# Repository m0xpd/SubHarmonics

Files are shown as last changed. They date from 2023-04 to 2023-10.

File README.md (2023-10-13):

# SubHarmonics 

'SubHarmonics' is a Eurorack module which generates two squarewaves ('A' and 'B') which are sub-harmonics of another signal, 'X'.

<p width=100%, align="center">

</p>

The signal X is either  
i) generated by the module's internal Voltage Controlled Oscillator  
or  
ii) is derived from an external signal applied to the module's 'Ext X In' input.

The sub-harmonics are generated by hardware dividers, which divide the frequency of X by integer divisors (m, n) of 2, 4, 6, 8, 10, 12, 14, 16 or 18,
giving the unit a range of a little over four octaves (18 ≈ 2 <sup> 4.17 </sup> ). 

These divisors (m := f <sub> x </sub> / f <sub> A </sub>, n := f <sub> x </sub> / f <sub> B </sub>) are voltage controlled - they can be set by potentiometers or by control voltages applied from external sources.

It is seen that the signals A and B are themselves related in frequency by 'the ratio of two small integers' (m/n). So, in addition to each being 
sub-harmonics of X, the ratio between A and B often falls at a musically useful interval; 
<p align="center">
'SubHarmonics' generates harmony as well as bass.
</p>

Other applications of 'SubHarmonics' in Clock Division and Rhythm Generation are described [here.](https://github.com/m0xpd/SubHarmonics/blob/main/Applications/ClockDivision_and_RhythmGeneration.md)

### Internal Modulators

SubHarmonics includes a pair of internal modulators, which combine the A and B signals together (through an OR and an Exclusive OR operation) to
exploit and develop the harmonic relationship between A and B into a richer sound. The OR modulation is equivalent (for these signals A, B) to simple
amplitude modulation, as performed by (e.g.) an AND gate, whilst the Exclusive OR modulation implements the balanced modulation of A with B (as in a 
'ring modulator'). I described the equivalence of OR and AND gates as modulators for the special class of 'antipalindromic' inputs (such as the present 
A and B signals) at tedious length [here.](http://m0xpd.blogspot.com/2023/03/logic-gates-and-modulation-curiosity.html)

The two different modulation results are combined in a voltage-controlled crossfader circuit (controlled by a potentiometer or an external CV input) 
to give a single output which offers a choice OR A MIX of the modulation types at the 'Mod Mix' output.

An introductory video, demonstrating SubHarmonics' features, is available [here](https://youtu.be/j_IT1Ucp6_4)

### Setup

There are two presets that need adjustment on completion of the module to setup for use. Both are located on the topside of the Main Board.

TR2 (a multi-turn 1k preset) controls the 1V/Octave tracking. It should be set by connecting the module to a reliable source of pitch CV signals and monitoring the outputs. I use octave outputs from a BeatStep Pro (you can use a keyboard with CV pitch outputs or simply a known voltage source) and listen to the pitch change. I find it easy to tune octaves by ear but, if you are uncertain, use a tuner or frequency counter.

TR1 (a single turn 100k preset) controls the balance of the modulation mix crossfader. To set it properly requires access to an oscilloscope to see the 'Mod Mix' output waveform. If you have no access to a 'scope, set TR1 to about 60kΩ.

If you do have a 'scope, set the divisors to m=2, n=6 (using the front panel controls) and the frequency to an arbitrary value (around 300Hz). View the 'A' and 'Mod Mix' outputs on the 'scope. Adjust TR1 until you see these waveforms when you put the Mix control at extreme ends of its travel (or, equivalently, apply 0V or 5V CV signals to the Mix input):

<p align="center", width=100%>

</p>

(the yellow trace is the 'A' output, which stays the same in this setup process and is included only as a 'reference', the blue trace is the 'Mod Mix' output, which will change when you adjust TR1)  

[If you do not see this waveform on the ModMix output with these settings, it may be due to the phase relationship between the dividers - if this is the case, change the value of 'n' using the potentiometer all the way up to 18 and back to 6 and see if the phase is re-aligned. This is perfectly normal and is not a fault - there is another 'mode' of the system in the m=2, n=6 configuration to that illustrated above.]

Note that the 'Mod Mix' output is inverted (it runs 0 to approx -4V); there wasn't a spare op-amp stage to restore polarity after the crossfader. 
This doesn't matter in ordinary applications; the ear is insensitive to the inversion and it will sound the same! There are, however, some implications of this inversion which are important to the 'time-domain' applications discussed [here.](https://github.com/m0xpd/SubHarmonics/blob/main/Applications/ClockDivision_and_RhythmGeneration.md)

### Miscellaneous Details

The sub-harmonic generation and all signal processing is performed in hardware. 

A small (PIC) microcontroller is used to read the potentiometers and CV inputs and set the dividers. 

Details of the two PCBs and front panel are provided in the [Hardware](https://github.com/m0xpd/SubHarmonics/tree/main/Hardware) folder. Code for 
the 16F676 PIC is presented in the [Controller](https://github.com/m0xpd/SubHarmonics/tree/main/Controller) folder.

SubHarmonics is:  
12HP wide,   
requires 38mm behind the front panel (with the power header fitted) and  
draws 13.5mA from the 12V rail and 5mA from the -12V rail.  

The design is published under a Creative Commons CC BY-SA 4.0 [License](https://github.com/m0xpd/SubHarmonics/blob/main/LICENSE.txt).

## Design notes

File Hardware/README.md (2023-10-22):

# Hardware
This folder contains hardware descriptions of the 'SubHarmonics' module.

The information is presented as EAGLE 'sch' and 'brd' files for the two PCBs (in the [PCBs folder](https://github.com/m0xpd/SubHarmonics/tree/main/Hardware/PCBs) ) and as a small Kicad project for the front panel (in
the FrontPanel folder).

SubHarmonics is implemented in two modules, each of which has its own PCB. There is a Main Board, hosting the majority of the electronics and
a Control Board, which contains all the front panel components including the division indicator LEDs and associated decoders.

## Main Board Description

The Main Board schematic is available [here](https://github.com/m0xpd/SubHarmonics/blob/main/Hardware/SubHarmonics%20Main%20Board%20Schematic%20v2.png) (or by clicking on the graphic below)

<p align='center' width=100%>

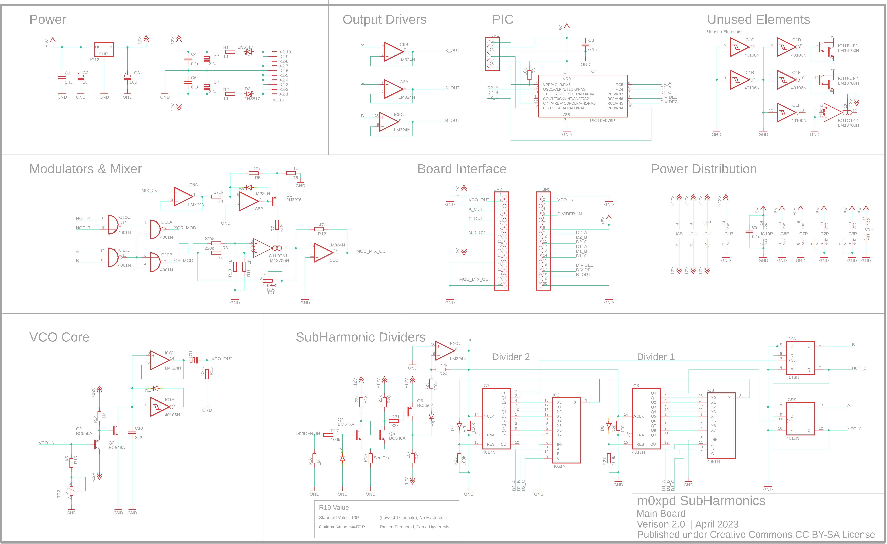
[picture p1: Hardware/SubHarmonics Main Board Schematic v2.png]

</p>

The VCO was inspired by the ['Shapes VCO' design by Moritz Klein](https://www.youtube.com/watch?v=QBatvo8bCa4), subsequently used in his VCO for the [Erica Synths Edu DIY VCO](https://www.ericasynths.lv/shop/diy-kits-1/edu-diy-vco/). Since developing 'SubHarmonics', I have learned that the core of the 40106 VCO was not a Klein original, but had been proposed earlier by Mark Shaner (a.k.a. "Synthmonger"), who published the idea [here](https://electro-music.com/forum/topic-28799.html) back in 2008.

The output of this 'Shaner' 40106 VCO - or the input from an external 'X' source - is applied to the 'Divider_In' input of the SubHarmonic Dividers, the input stages of which produce a 0 : 5V pulse at node 'X' on the schematic. There is a detailed description of the derivation of this pulse signal, including
discussion of options to set shared emitter resistor R19 to either maximise input sensitivity or enable a degree of noise immunity, [here.](https://github.com/m0xpd/SubHarmonics/blob/main/Hardware/Graphics/Input%20Stage%20Switching%20Behaviour.md) 

The system was designed around 'available materials' I found lying around my bench - in this case, mainly CD4000-series CMOS logic devices. 

The divisions in each of the two channels are achieved by a CD4015 (Decade counter) and a CD4051 (Analog Mux/Demux) in conventional 
configuration. The divisor is set by a PIC microcontroller, which reads a potentiometer or a CV input signal and decodes the voltage (0-5V) into 
one-of-8 settings for the dividers.

A further divide-by-2 stage, implemented in a CD4013 (D-type SR flip-flop) applied to the outputs of the dividers adds another octave of division 
(necessary to implement the m=2 setting on the A channel).

The outputs of the dividers, A and B (and their complements, not_A and not_B) are fed to two modulators, implemented in a quad NOR package (CD4001).

The results of the OR and XOR operations are mixed in a voltage-controlled crossfader, implemented in half an LM13700.

The [schematic](https://github.com/m0xpd/SubHarmonics/blob/main/Hardware/SubHarmonics%20Main%20Board%20Schematic%20v2.png) and [BoM](https://github.com/m0xpd/SubHarmonics/blob/main/Hardware/PCBs/SubHarmonics%20Main%20Board%20BoM%20v2.txt) show LM324 quad op-amps. These work fine in this application, but you can substitute the ubiquitous TL074 if you prefer. 

The Main Board includes an In-Circuit Serial Programming (ICSP) interface (JP1) to facilitate programming the PIC.

There is a [.sch](https://github.com/m0xpd/SubHarmonics/blob/main/Hardware/PCBs/SubHarmonics%20Main%20Board%20v2.sch) file, a [.brd](https://github.com/m0xpd/SubHarmonics/blob/main/Hardware/PCBs/SubHarmonics%20Main%20Board%20v2.brd) file and a [BoM](https://github.com/m0xpd/SubHarmonics/blob/main/Hardware/PCBs/SubHarmonics%20Main%20Board%20BoM%20v2.txt) for the Main Board in EAGLE format in the [PCBs folder](https://github.com/m0xpd/SubHarmonics/tree/main/Hardware/PCBs).

## Control Board Description

The Control Board schematic is available [here](https://github.com/m0xpd/SubHarmonics/blob/main/Hardware/Control%20Board%20Schematic.png) (or by clicking on the graphic below)
<p align='center' width=100%>

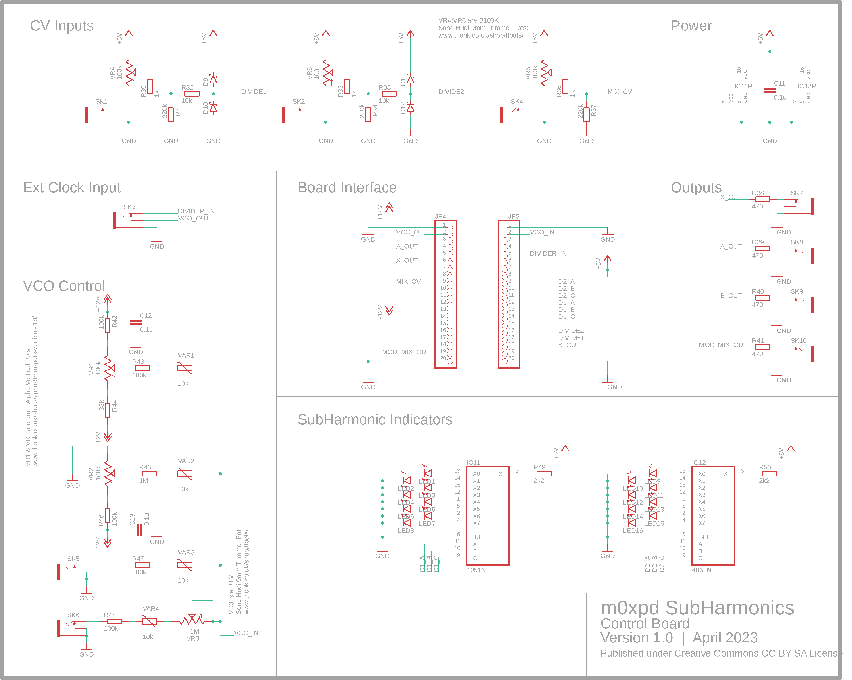
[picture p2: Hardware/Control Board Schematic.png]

</p>

In addition to controls, inputs and outputs, the Control Board hosts the division indicator LEDs and decoders to control these (which again use 
CD4051 analog demuxers).

As well as to CV inputs for Pitch and FM, there are CV inputs for the divisors m and n and for the modulation mix. These last three are designed 
to operate over a range of 0 to 5V, but are protected such that voltages outside these limits will cause no damage.

A 0V input on the modulation mix CV input gives the XOR modulation and a 5V input gives the OR modulation (which is spectrally richer, as it includes the
harmonics of A and B as well as the sum and difference harmonics). An intermediate control voltage gives a mix of both modulation types.

There is a [.sch](https://github.com/m0xpd/SubHarmonics/blob/main/Hardware/PCBs/SubHarmonics%20Control%20Board%20v1.sch) file, a [.brd](https://github.com/m0xpd/SubHarmonics/blob/main/Hardware/PCBs/SubHarmonics%20Control%20Board%20v1.brd) file and a [BoM](https://github.com/m0xpd/SubHarmonics/blob/main/Hardware/PCBs/SubHarmonics%20Control%20Board%20v1%20BoM.txt) for the Control Board in EAGLE format in the [PCBs folder.](https://github.com/m0xpd/SubHarmonics/tree/main/Hardware/PCBs)

The Main and Control boards are joined by two 20-way 0.1 inch pitch headers. These have been specified with electrical redundancy (several pins are 
unused) to provide mechanical stability and security in assembling the module.

The completed PCBs are seen in the photo below, which shows the Main Board from both sides and the Control Board from the 'top' side (the front panel 
components all are mounted on the 'bottom' side).
<p align='center' width=100%>



</p>
 
## Front Panel

<p align='center' width=100%>
SubHarmonics Front Panel

</p>

A simple Kicad project defining a Front Panel for the module is available in the [FrontPanel folder.](https://github.com/m0xpd/SubHarmonics/tree/main/Hardware/FrontPanel)

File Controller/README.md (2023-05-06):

# Controller Code for SubHarmonics

Code for the PIC 16F676 microcontroller is found [here.](https://github.com/m0xpd/SubHarmonics/blob/main/Controller/Divide_Controller.c)

It was developed in C in Microchip's [MPLAB IDE](https://www.microchip.com/en-us/tools-resources/develop/mplab-x-ide).

The [code](https://github.com/m0xpd/SubHarmonics/blob/main/Controller/Divide_Controller.c) should be placed within an MPLAB project for the 16F676, built and programmed into the device using a suitable programmer.

I programmed the first PIC using my [PICKit 3](https://www.microchip.com/en-us/development-tool/PG164130) and my old [k1el PIC Programming Adapter](https://hamcrafters2.com/PICPGM.html), but I designed an In-Circuit Serial Programming 
Interface into the SubHarmonics Main Board, so you can program directly on the module:
<p align='center', width=100%>

</p>

The PICKit3 supplies easily enough current to power the module; no special setting or modification needs to be made to the module during programming.

I will try to post a complete MPLAB project (rather than just the C code) and a .hex file in this repository once I've figured out how to do it.

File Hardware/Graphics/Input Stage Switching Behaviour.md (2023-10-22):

# Input Switching Behaviour

The pulses applied to the SubHarmonics' divider chains are derived from either 
* the internal VCO or
* the "Ext X In" input 

via the input stage formed of Q4 & Q5, Q6 and IC6C.

These active elements amplify the input and form it into a pulse signal, which is saturated at levels of the +/- 12V 
power rails (at the collector of Q6) and subsequently half-wave rectified, inverted and attenuated (by D6 and IC6C)
to pulses of approximately 5V.

The Q4, Q5 stage is a stripped-down version of a conventional transistor [Schmitt Trigger.](https://en.wikipedia.org/wiki/Schmitt_trigger) 

In the present application, the input stage is required to have high sensitivity (a low value of 'HIGH THRESHOLD'), 
as the output of the VCO is rather small (~1.5 V peak). Accordingly, a low magnitude of the emitter resistor 
R19 = 10R was initially chosen in order to obtain a switching threshold of 0.85V.

Unfortunately, this 10R resistor destroys almost all the hysteresis which is the defining property of a Schmitt Trigger.

The images below show the switching behaviour of SubHarmonics with R19 at values of 10R and 470R.

<p width=100%, align="center">
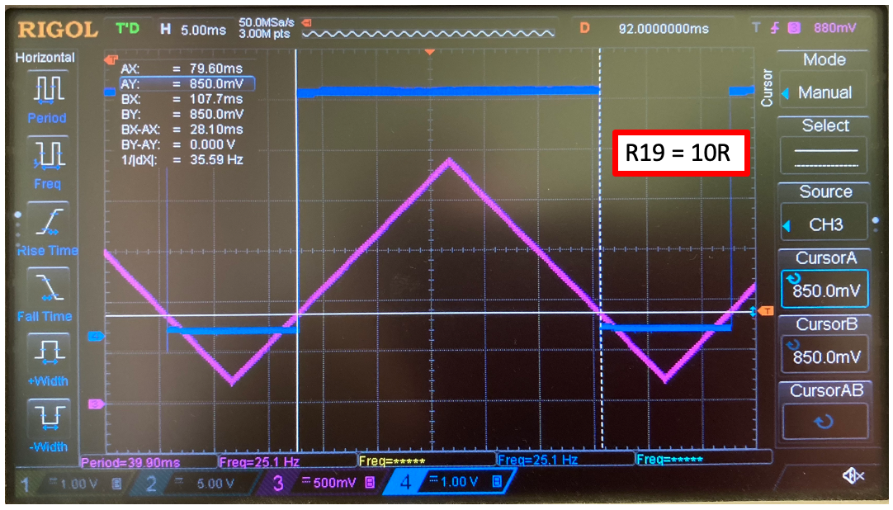
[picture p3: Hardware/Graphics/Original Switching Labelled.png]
 
</p>
<p width=100%, align="center">
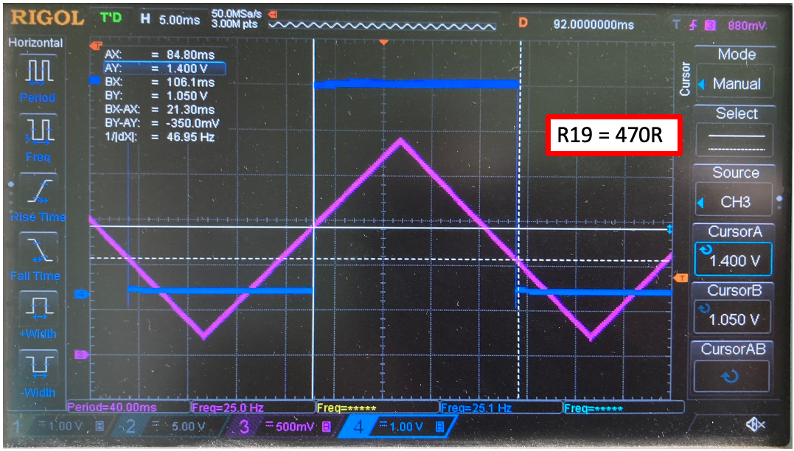
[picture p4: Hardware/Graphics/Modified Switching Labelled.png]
 
</p>

You can see that the 10 Ohm resistor results in switching of the 'X output' (Blue trace) at the same (0.85V) point on the upward 
and downward transistions of the External X input (Cyan trace). The switching point is shown by the 'scope's "A cursor", which 
superimoses a (white) horizontal line on the screen and records a numerical value at top left. The HIGH and LOW THRESHOLDS are 
equal and there is no hysteresis.

The 470 Ohm resistor results in switching at 1.4V on upward transitions of the input (HIGH THRESHOLD = 1.4V, shown by the 'A cursor') 
whilst switching on the downward transition occurs at the lower input voltage of ~1.05V (LOW THRESHOLD = 1.05V, shown by the 'B cursor',
which adds a dashed white horizontal line). There is now approximatey 0.35V of hysteresis.

Although it is possible to further increase the emitter resistor magnitude in other applications (and thereby achieve greater hysteresis),
this is won at the expense of still greater increases in the value of HIGH THRESHOLD. I have found that 470R is the largest 
value that can be used in SubHarmonics in order that the signal from the internal VCO is still detected. 

If we deliberately add 350mV (pk-pk) of noise:

<p width=100%, align="center">
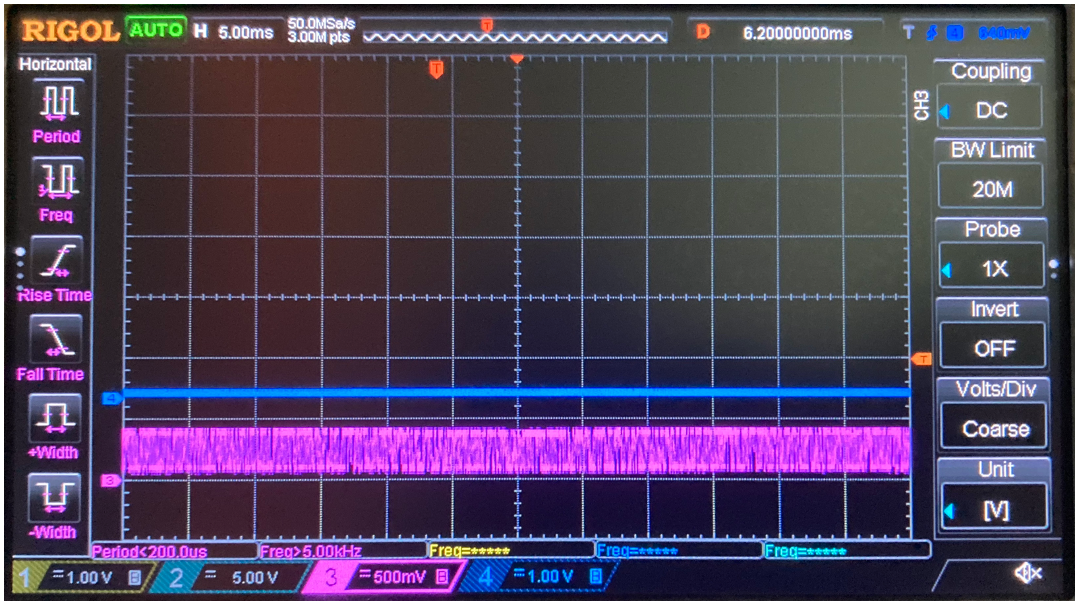
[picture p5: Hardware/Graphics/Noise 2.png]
 
</p>
to the external X input, the potential benefits of the Schmitt Trigger action become clear.

The modified (R19=470R) circuit operates well in the presence of the noise,

<p width=100%, align="center">
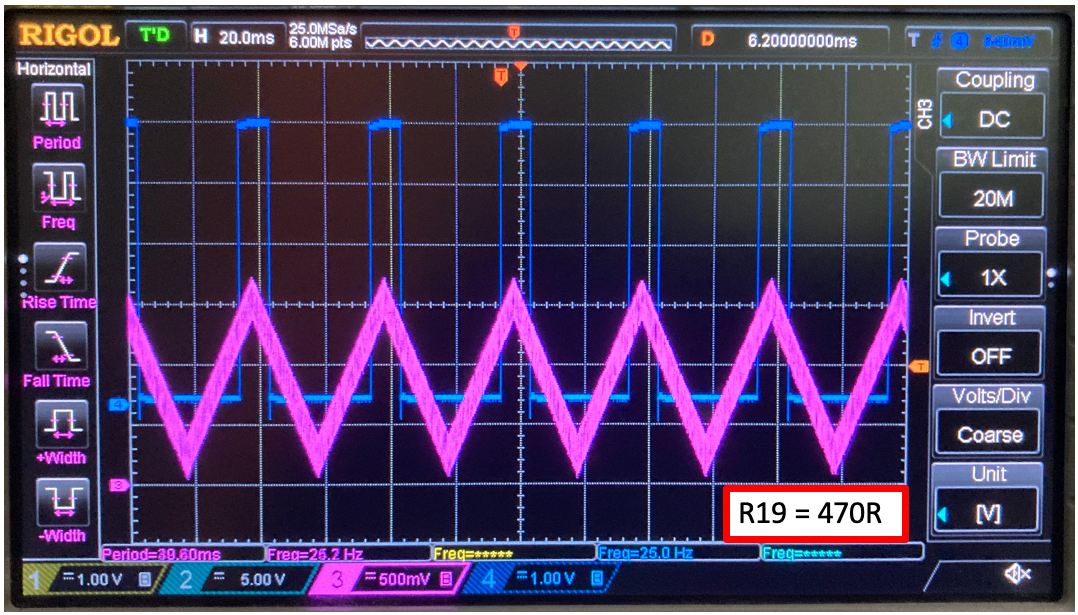
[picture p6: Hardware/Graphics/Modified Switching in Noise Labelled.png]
 
</p>

with nice, clear, regular transitions of the (Blue) X output trace.

However, the circuit in original configuration (R19 = 10R) suffers visible disruption of the (Blue) X output 
with the same noisy external X input
<p width=100%, align="center">
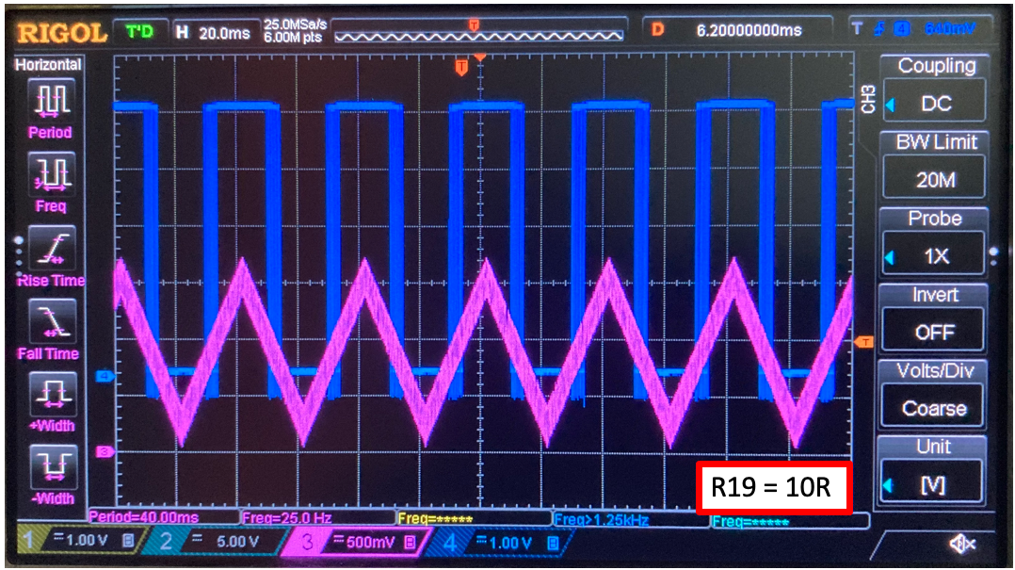
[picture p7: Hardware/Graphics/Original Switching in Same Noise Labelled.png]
 
</p>

This can be made to LOOK more dramatic by reducing the input signal (and keeping the noise amplitude the same). 
<p width=100%, align="center">
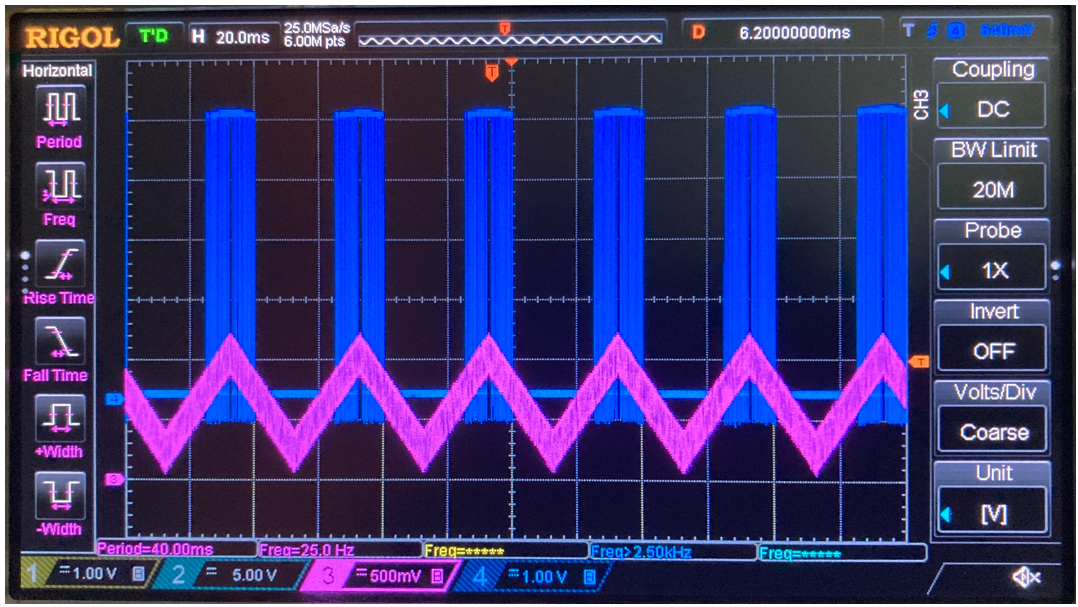
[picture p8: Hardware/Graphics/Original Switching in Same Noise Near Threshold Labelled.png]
 
</p>

Note that it is not the peak 'signal' to noise ratio that is important; rather it is the THRESHOLD to noise ratio. 

What we did most significantly in the figure above was reduce the GRADIENT of the input signal around the 
threshold voltage, so we changed the effective timescale; the system spent more time around the decision point
and there was more opportunity for the noise to cause false triggers, which showed up as visible lines on the 'scope.

# Choosing a value for R19

So, if you build a 'SubHarmonics' module you have a choice.
* you could opt for the original R19 = 10R value, with the best possible input sensitivity (switching threshold = 0.85V), 
but NO Schmitt Trigger action, or
* you could opt for the maximum R19 = 470R value, with a loss of input sensitivity (HIGH THSRESHOLD = 1.4V) and ~0.35V 
Schmitt Trigger 'hysteresis', or
* you could opt for a mid-point compromise.

I have built both versions (R19 = 10R, R19 = 470R). Both work well.

I used the original (R19=10R) for six months and never noticed any problem with noise immunity on the 'Ext X In' input 
which made me wish there was Schmitt Trigger action. However, we are used to having high amplitude, noise-free signals
avaialble from our oscillators, so that's hardly surprising.

On the other hand, now I've enabled the Schmitt Trigger functionality, the same high amplitude oscillator and clock 
signals can still trigger the SubHarmonics module at the 'Ext X In' input but I get the "extra insurance" of 0.35V of 
noise immunity at no additional expense (a 470R resistor is no more expensive than a 10R resistor - or even a wire link!).

So - all things considered - I guess I prefer the revised version with R19 = 470R. 

You must make your own choice.
 
# Acknowledgement

All this interest in the magnitude of R19 and the reinstatement of Schmitt Trigger action was prompted by a question raised
by Yves Chartier, and subsequent discussion. I am grateful for Yves' valuable contribution and support.

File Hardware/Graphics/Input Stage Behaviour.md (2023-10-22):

# SubHarmonics' X Input Stage behaviour

The pulses applied to the harmonic divider chains is derived from either the internal VCO or the External input 
via the input stage formed of Q4 & Q5, Q6 and IC6C.

These active stages amplify the input and form it into a pulse signal, which is saturated at levels of the +/- 12V 
power rails (at the collectro of Q6) and subsequently half-wave rectified, inverted and attenuated (by D6 and IC6C)
to a pulse a little over 5V.

The Q4, Q5 stage is a stripped-down version of a conventional transistor [Schmitt Trigger](https://en.wikipedia.org/wiki/Schmitt_trigger) stage. 

In this applcation, the stage is required to have high sensitivity (a low value of 'HIGH THRESHOLD'), as the output 
of the VCO is rather small (~1.5 V). Accordingly, a low magnitude of the emitter resistor R19 = 10R was initially 
chosen, which gave a switching threshold of 0.85V.

Unfortunately, this 10R resistor destroys almost all the hysteresis which is the defining property of the Schmitt Trigger.

The images below show the switching behaviour of SubHarmonics with R19 at values of 10R and 470R.

<p width=100%, align="center">
 
</p>
<p width=100%, align="center">
 
</p>

You can see that the 10 Ohm resistor results in swithing (of the  (Blue) output at the same (0.85V) point on the upward 
and downward transistions of the (Cyan) input - i.e. the HIGH and LOW THRESHOLDS are equal and there is no hysteresis.

The 470 Ohm resistor results in switching at 1.4V on upward transitions of the input (HIGH THRESHOLD = 1.4V) whilst swithing
on the downward transition occurs at the lower input voltage of ~1.05V (LOW THRESHOLD = 1.05V). There is now approximatey 
0.35V of hysteresis.

Although it is possible to further increse the emitter resistor magnitude in other applications (and achieve greater hysteresis),
this is won at the expense of still greater increases in the value of HIGH THRESHOLD. I have found that 470R is the greatest 
value that can be used in SubHarmonics in order that the signal from the internal VCO is still detected. 

If we deliberately add 350mV of noise:

<p width=100%, align="center">
 
</p>
to the input, the potential benefits of this Schmitt Trigger action become clear.

The modified (R19=470R) circuit operates well in the presence of the noise,

<p width=100%, align="center">
 
</p>

with nice, clear, regular yransitions of the (Blue) output trace.

However, the circuit in original configuration (R19 = 10R) suffers visible disruption of the (Blue) output 
with the same input
<p width=100%, align="center">
 
</p>

This can be made to LOOK more dramatic by reducing the input signal (and keeping the noise amplitude the same). 
<p width=100%, align="center">
 
</p>

Note that it is not the peak 'signal' to noise ratio that is important; rather it is the THRESHOLD to noise ratio. 
What we did most significantly in the figure above was change the GRADIENT of the input signal around the 
threshold voltage, so we changed the effective timescale; the system spent more time around the decision point
and there was more opportunity for the noise to cause false triggers, which showed up as visible lines on the 'scope.

So, if you build a 'SubHarmonics' module you have a choice.
* you could opt for the original R19 = 10R value, with the best possible input sensitivity (switching threshold = 0.85V), 
but NO Schmitt Trigger action, or
* you could opt for the maximum R19 = 470R value, with a loss of input sensitivity (HIGH THSRESHOLD = 1.4V) and ~0.35V 
Schmitt Trigger 'hysteresis', or
* you could opt for a mid-point compromise.

I have built both versions.

I used the original (R19=10R) for six months and never noticed any problem with noise immunity on the 'Ext X In' input 
which made me wish there was Schmitt Trigger action. However, we are used to having high amplitude, noise-free signals
avaialble from our oscillators, so that's hardly surprising.

On the other hand, now I've added the extra Schmitt Trigger functionality, the same high amplitude oscillator and clock 
signals can still trigger the SubHarmonics input but I get the "extra insurance" of 0.35V of noise immunity at no additional
expense (a 470R resistor is no more expensive than a 10R resistor - or even a wire link!).

So - all things considered - I guess I prefer the revised version with R19 = 470R. You must make your own choice.
 
# Acknowledgement

All this interest in the magnitude of R19 and the reinstatement of Schmitt Trigger action was prompted by a question raised
by Yves Chartier, and subsequent discussion. I am grateful for Yves' valuable contribution and support.

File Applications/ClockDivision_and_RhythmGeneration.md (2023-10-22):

If you reduce the frequency of SubHarmonics' VCO or apply a clock signal to the 'Ext X In' from an LFO or similar source,
you enable a range of opportunities in **Clock Division** and **Rhythm Generation**.

## SubHarmonics as a Clock Divider 

The two divider chains of SubHarmonics will offer direct division of the X clock by ratios of:

2, 4, 6, 8, 10, 12, 14 & 16   (for the A output) 

and

4, 6, 8, 10, 12, 14, 16, & 18 (for the B output)

These divisions can be set either by the manual m & n divisor controls or by CV inputs.

Many 'secondary' divisions can be established between A and B outputs. 

For example, with m=2 and n=6 the ratio between X and A is 1:2 and the ratio between X and B is 1:6, 
making the ratio between A and B 2:6 (1:3).

Similarly, other odd integer ratios can be established via this 'secondary' approach, such that all integer ratios up 
to ten can be achieved:

<p width=100%, align="center">

</p>

Similarly, even integer divisions from 10 to 18 can be achieved directly.

## Building Rhythm using SubHarmonics

Given the clock division described above, it is possible to take the divided clock signals and use them to trigger 
percussive sounds, making SubHarmonics a Rhythm Generator. 

The complexity of the rhythms generated is greatly increased if logic operations (AND, OR XOR, etc) are performed between 
the clock signals (X, A & B) to derive more interesting patterns.

Remember that SubHarmonics has it's own pair of internal logic modulators, which combine the A and B signals (through OR 
and XOR functions). These are combined at the 'ModMix' output and can be selected by the 'Mix' control (or by CV). 
This was desiged for use when the ModMix output was interpreted as an 'analog' audio signal (rather than a Boolean switching 
signal). Accorindingly, there are a couple of issues for the present 'Rhythm Generator' application:

1) Signals from the 'ModMix' output are inverted, running from 0 to -3.75V. To use as conventional (positive true) logic 
signals, they must be inverted. I use a Voltage Processor to perform this inversion ('Maths' or any capable processor can 
do the job). You can just shift the level (rather than do an inversion) but this results in a different function - interesting
as it will generate a different pattern and potentially useful if you don't have the resource to do the actual inversion.

2) There is no real meaning in the mixed signals for intermediate settings of the 'Mix' control in this context; the mix 
is only relevant to the output when used in 'analog' applications - so switching between the two modulators is best achieved 
with changes between extreme settings of the 'Mix' control (0 or 5V CV) to give either the XOR or the OR modulator.

The consequence of changing the Mix control is illustrated in this example:

<p width=100%, align="center">

</p>

The 'scope traces show: 
* the X signal (top trace, Yellow)
* the A subharmonic, m=8, (second trace, Cyan)
* the B subharmonic, n=16, (third trace, Blue)
* the Mix output, (bottom trace, Purple)

The left-hand image shows the response with the OR modulator (Mix control fully clockwise or 5V CV Input) and the right-hand 
trace shows the response with the XOR modulator (Mix control fully counter clockwise or 0V CV input).

Finally, AND **MOST IMPORTANTLY**, the two dividers are independant. This allows you to deliberately change the 'phase' between 
the SubHarmonics A & B. This introduces **additional variation in rhythm generation**.

Variation is achieved by briefly changing the setting of one of the divisors (m or n), which introduces a relative delay 
(or advance, depending if you increase or decrease the divisor) relative to the other subharmonic, thereby changing the 
'phase'. 

The process is not deterministic, but you will soon 'get the feel for it'. 

I prefer to adjust the largest divisor (i.e. max(m,n)) by one step for a couple of seconds and listen for the result before returning 
to the nominal value.

There is a video, demonstrating these ideas with two percussion voices, [here](https://youtu.be/6WWO7RoppK4).

The period, T0, of a pattern generated by mixing subharmonics m & n is given by:

T0 = Tx.m.n/*gcd(m,n)*

where Tx is the clock period and *gcd()* is the [greatest common divisor.](https://en.wikipedia.org/wiki/Greatest_common_divisor)

Some examples are tabulated below:

<p width=100%, align="center">

</p>

You can easily set up a reasonably complex rhythm source, with triggers from A, B, logical operations on A and B (I like to 
use an external AND gate driven by A and B, occasionally with extra inputs - as there is no AND modulator internal to SubHarmonics) 
and, of course, ModMix. 

You establish a basic pattern by setting m & n and introduce variation by 
* changing the 'phase' and 
* switching between the internal modulators.

---

**SubHarmonics** can be used to generate 
* melody, using its VCO,
* bass, using its dividers,
* harmony, using its modulators, 
* **and rhythm**, using the process described above.

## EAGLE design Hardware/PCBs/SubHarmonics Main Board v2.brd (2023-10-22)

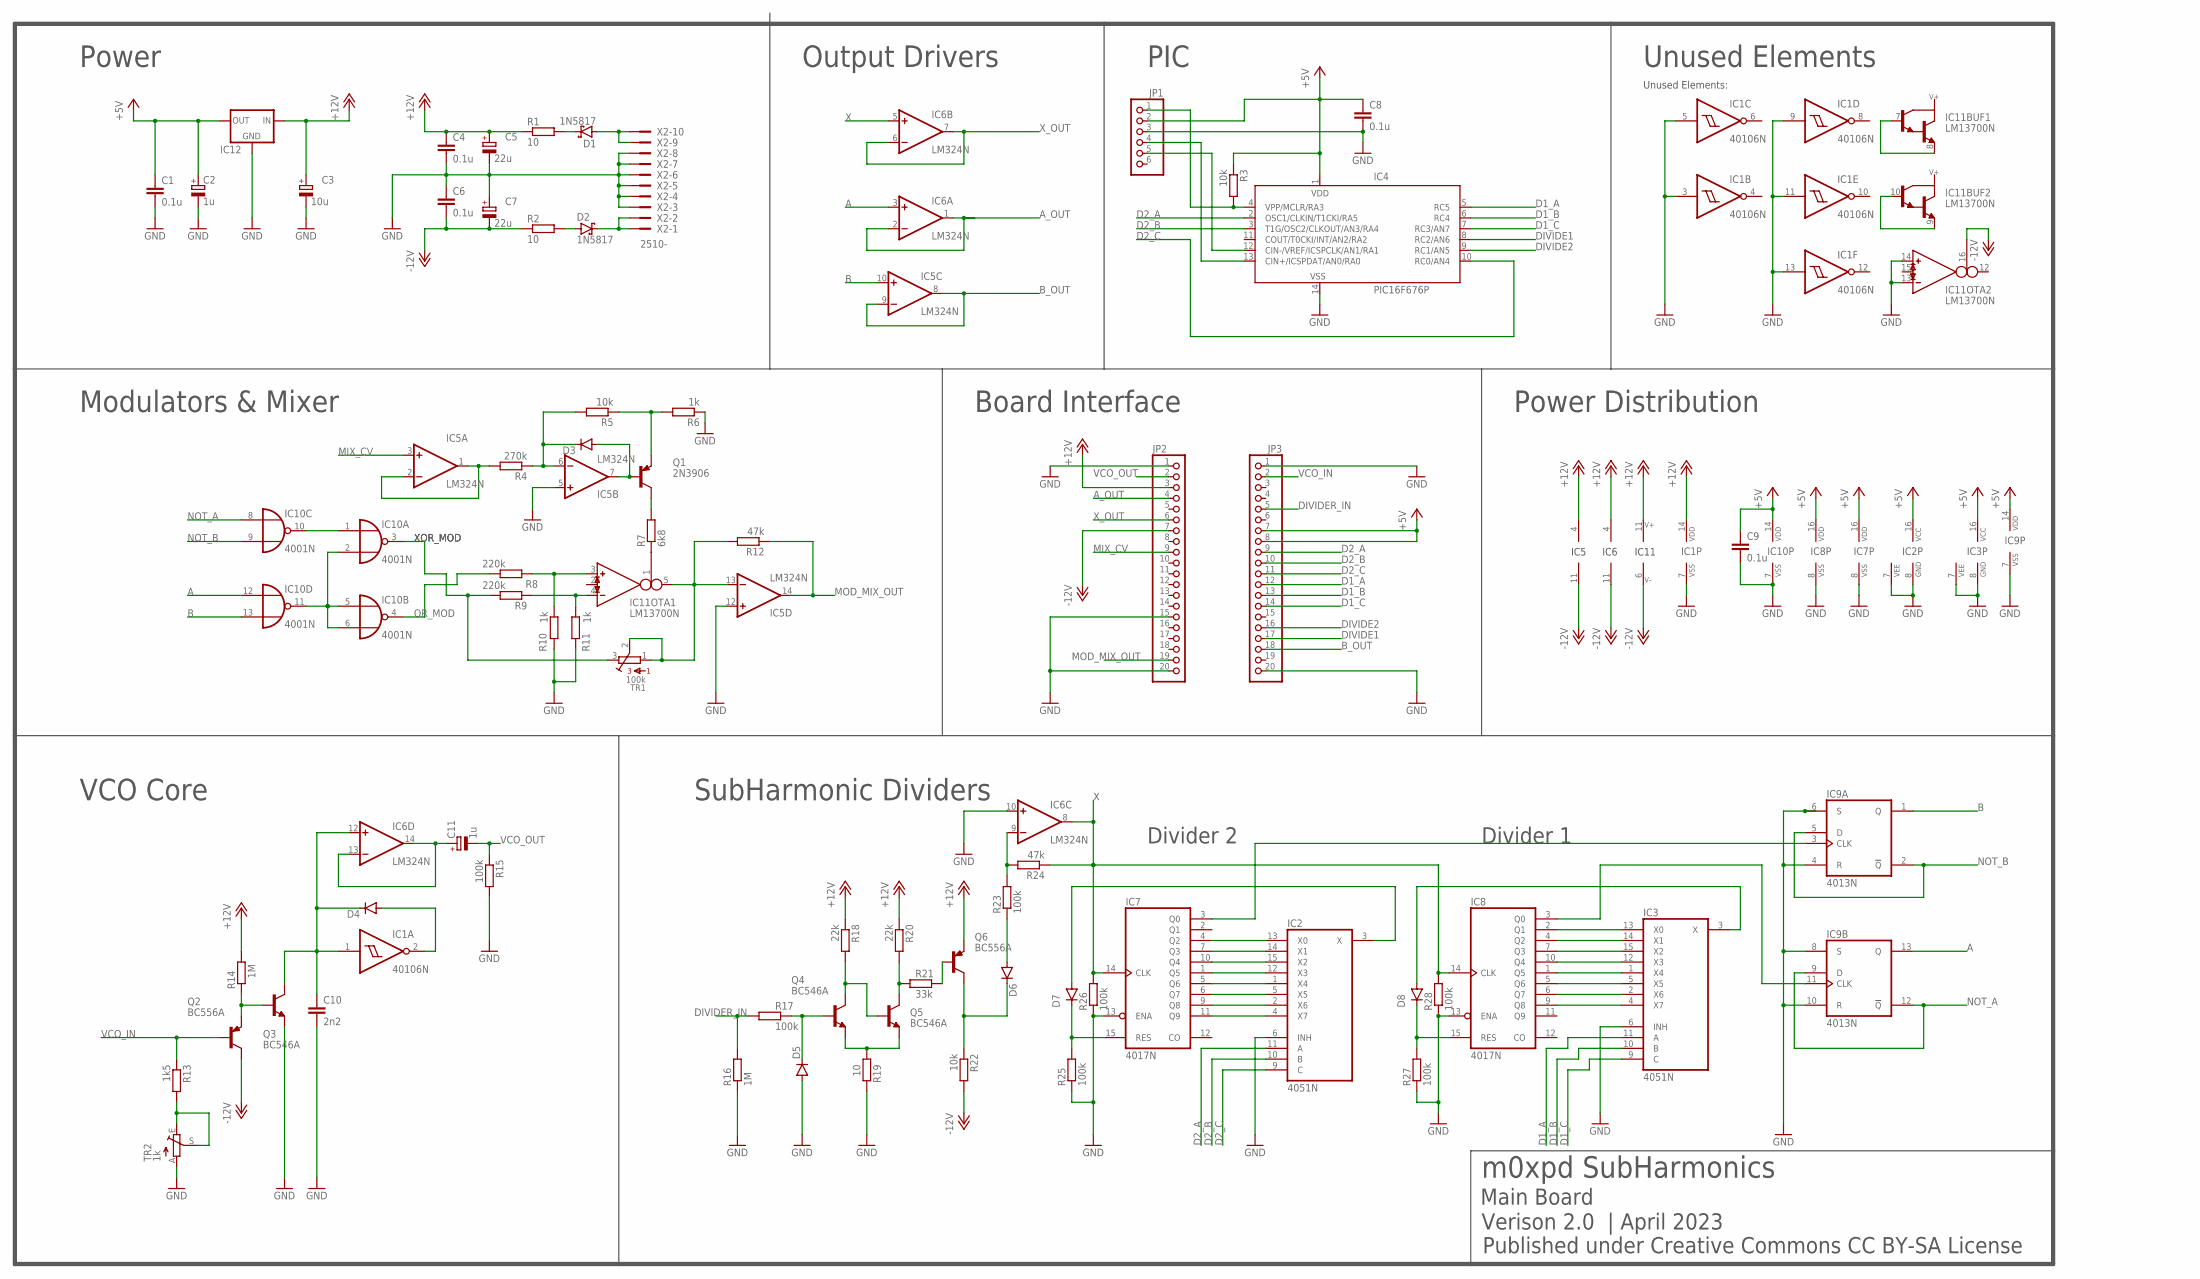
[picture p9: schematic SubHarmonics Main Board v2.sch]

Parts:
C1, C4, C6, C8, C9: 0.1u; C050-025X075
C2, C11: 1u; E2,5-5
C3: 10u; E2,5-5
C5, C7: 22u; E2,5-5
C10: 2n2; C050-030X075
D1, D2: 1N5817; DO35-7
D3, D4, D5, D6, D7, D8: 1N4148DO35-7; DO35-7
IC1: 40106N; DIL14
IC2, IC3: 4051N; DIL16
IC4: PIC16F676P; DIL14
IC5, IC6: LM324N; DIL14
IC7, IC8: 4017N; DIL16
IC9: 4013N; DIL14
IC10: 4001N; DIL14
IC11: LM13700N; DIL16
IC12: 78LXX
JP1: PINHD-1X6; 1X06
JP2, JP3: PINHD-1X20; 1X20
Q1: 2N3906; TO92
Q2, Q6: BC556A; TO92-EBC
Q3, Q4, Q5: BC546A; TO92-EBC
R1, R2, R19: 10; 0204/7
R3, R5, R22: 10k; 0204/7
R4: 270k; 0204/7
R6, R10, R11: 1k; 0204/7
R7: 6k8; 0204/7
R8, R9: 220k; 0204/7
R12, R24: 47k; 0204/7
R13: 1k5; 0204/7
R14, R16: 1M; 0204/7
R15, R17, R23, R25, R26, R27, R28: 100k; 0204/7
R18, R20: 22k; 0204/7
R21: 33k; 0204/7
TR1: 100k; BOURNS_3362P_TRIMMER
TR2: 1k; B64Y
X2: 2510-; PAK100/2500-10

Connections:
+5V: C1.1, C2.+, C8.1, C9.1, IC2.16 (VCC), IC3.16 (VCC), IC4.1 (VDD), IC7.16 (VDD), IC8.16 (VDD), IC9.14 (VDD), IC10.14 (VDD), IC12.OUT, JP1.2, JP3.7, JP3.8, R3.1
+12V: C3.+, C4.1, C5.+, IC1.14 (VDD), IC5.4 (V+), IC6.4 (V+), IC11.11 (V+), IC12.IN, JP2.3, Q6.E, R1.1, R14.2, R18.1, R20.1
-12V: C6.2, C7.-, IC5.11 (V-), IC6.11 (V-), IC11.6 (V-), IC11.16 (I_BIAS), JP2.7, Q2.C, R2.1, R22.2
A: IC6.3 (+IN), IC9.13 (Q), IC10.12 (I0)
A_OUT: IC6.1 (OUT), IC6.2 (-IN), JP2.4
B: IC5.10 (+IN), IC9.1 (Q), IC10.13 (I1)
B_OUT: IC5.8 (OUT), IC5.9 (-IN), JP3.18
D1_A: IC3.11 (A), IC4.5 (RC5), JP3.12
D1_B: IC3.10 (B), IC4.6 (RC4), JP3.13
D1_C: IC3.9 (C), IC4.7 (RC3/AN7), JP3.14
D2_A: IC2.11 (A), IC4.2 (OSC1/CLKIN/T1CKI/RA5), JP3.9
D2_B: IC2.10 (B), IC4.3 (T1G/OSC2/CLKOUT/AN3/RA4), JP3.10
D2_C: IC2.9 (C), IC4.10 (RC0/AN4), JP3.11
DIVIDE1: IC4.8 (RC2/AN6), JP3.17
DIVIDE2: IC4.9 (RC1/AN5), JP3.16
DIVIDER_IN: JP3.5, R16.2, R17.1
GND: C1.2, C2.-, C3.-, C4.2, C5.-, C6.1, C7.+, C8.2, C9.2, C10.2, D5.A, IC1.3 (I), IC1.5 (I), IC1.7 (VSS), IC1.9 (I), IC1.11 (I), IC1.13 (I), IC2.6 (INH), IC2.7 (VEE), IC2.8 (GND), IC3.6 (INH), IC3.7 (VEE), IC3.8 (GND), IC4.14 (VSS), IC5.5 (+IN), IC5.12 (+IN), IC6.10 (+IN), IC7.8 (VSS), IC7.13 (ENA), IC8.8 (VSS), IC8.13 (ENA), IC9.4 (R), IC9.6 (S), IC9.7 (VSS), IC9.8 (S), IC9.10 (R), IC10.7 (VSS), IC11.13 (IN_N), IC11.14 (IN_P), IC12.GND, JP1.3, JP2.1, JP2.15, JP2.20, JP3.1, JP3.20, Q3.E, R6.1, R10.2, R11.2, R15.2, R16.1, R19.2, R25.1, R26.1, R27.1, R28.1, TR2.A, X2.3, X2.4, X2.5, X2.6, X2.7, X2.8
MIX_CV: IC5.3 (+IN), JP2.9
MOD_MIX_OUT: IC5.14 (OUT), JP2.19, R12.1
unnamed: IC2.2 (X6), IC7.9 (Q8)
unnamed: IC5.1 (OUT), IC5.2 (-IN), R4.2
unnamed: D7.C, IC7.15 (RES), R25.2
unnamed: D7.A, IC2.3 (X)
unnamed: IC2.13 (X0), IC7.4 (Q2)
unnamed: IC2.14 (X1), IC7.7 (Q3)
unnamed: IC2.15 (X2), IC7.10 (Q4)
unnamed: IC2.12 (X3), IC7.1 (Q5)
unnamed: IC2.1 (X4), IC7.5 (Q6)
unnamed: IC2.5 (X5), IC7.6 (Q7)
unnamed: IC2.4 (X7), IC7.11 (Q9)
unnamed: IC11.3 (IN_P), R8.1, R10.1
unnamed: D1.A, X2.9, X2.10
unnamed: D1.C, R1.2
unnamed: IC4.4 (VPP/MCLR/RA3), JP1.1, R3.2
unnamed: D8.C, IC8.15 (RES), R27.2
unnamed: D8.A, IC3.3 (X)
unnamed: IC11.7 (B), IC11.8 (E)
unnamed: IC3.14 (X1), IC8.4 (Q2)
unnamed: IC3.15 (X2), IC8.7 (Q3)
unnamed: IC3.12 (X3), IC8.10 (Q4)
unnamed: IC3.1 (X4), IC8.1 (Q5)
unnamed: IC3.5 (X5), IC8.5 (Q6)
unnamed: IC3.2 (X6), IC8.6 (Q7)
unnamed: IC3.4 (X7), IC8.9 (Q8)
unnamed: IC11.4 (IN_N), R9.1, R11.1
unnamed: D2.A, R2.2
unnamed: D2.C, X2.1, X2.2
unnamed: IC11.9 (E), IC11.10 (B)
unnamed: IC11.1 (I_BIAS), R7.1
unnamed: IC4.13 (CIN+/ICSPDAT/AN0/RA0), JP1.4
unnamed: IC4.12 (CIN-/VREF/ICSPCLK/AN1/RA1), JP1.5
unnamed: IC3.13 (X0), IC8.2 (Q1)
unnamed: IC8.3 (Q0), IC9.11 (CLK)
unnamed: IC7.3 (Q0), IC9.3 (CLK)
unnamed: R13.2, TR2.E, TR2.S
unnamed: D6.C, Q6.C, R22.1
unnamed: D6.A, R23.1
unnamed: D4.A, IC1.2 (O)
unnamed: C10.1, D4.C, IC1.1 (I), IC6.12 (+IN), Q3.C
unnamed: Q2.E, Q3.B, R14.1
unnamed: IC6.9 (-IN), R23.2, R24.2
unnamed: C11.+, IC6.13 (-IN), IC6.14 (OUT)
unnamed: Q4.E, Q5.E, R19.1
unnamed: IC10.1 (I0), IC10.10 (O)
unnamed: IC10.2 (I1), IC10.5 (I0), IC10.6 (I1), IC10.11 (O)
unnamed: D5.C, Q4.B, R17.2
unnamed: Q1.1 (C), R7.2
unnamed: D3.C, IC5.6 (-IN), R4.1, R5.2
unnamed: Q4.C, Q5.B, R18.2
unnamed: Q5.C, R20.2, R21.1
unnamed: D3.A, IC5.7 (OUT), Q1.2 (B)
unnamed: Q1.3 (E), R5.1, R6.2
unnamed: Q6.B, R21.2
unnamed: IC5.13 (-IN), IC11.5 (OUT), R12.2, TR1.1, TR1.2
NOT_A: IC9.9 (D), IC9.12 (!Q), IC10.8 (I0)
NOT_B: IC9.2 (!Q), IC9.5 (D), IC10.9 (I1)
OR_MOD: IC10.4 (O), R8.2
VCO_IN: JP3.2, Q2.B, R13.1
VCO_OUT: C11.-, JP2.2, R15.1
X: IC6.5 (+IN), IC6.8 (OUT), IC7.14 (CLK), IC8.14 (CLK), R24.1, R26.2, R28.2
XOR_MOD: IC10.3 (O), R9.2, TR1.3
X_OUT: IC6.6 (-IN), IC6.7 (OUT), JP2.6

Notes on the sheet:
Unused Elements:
Divider 1
Divider 2
m0xpd SubHarmonics
Main Board
Verison 2.0 | April 2023
Published under Creative Commons CC BY-SA License
VCO Core
SubHarmonic Dividers
Modulators & Mixer
Power
Output Drivers
PIC
Unused Elements
Power Distribution
Board Interface
IC5
IC6
IC11

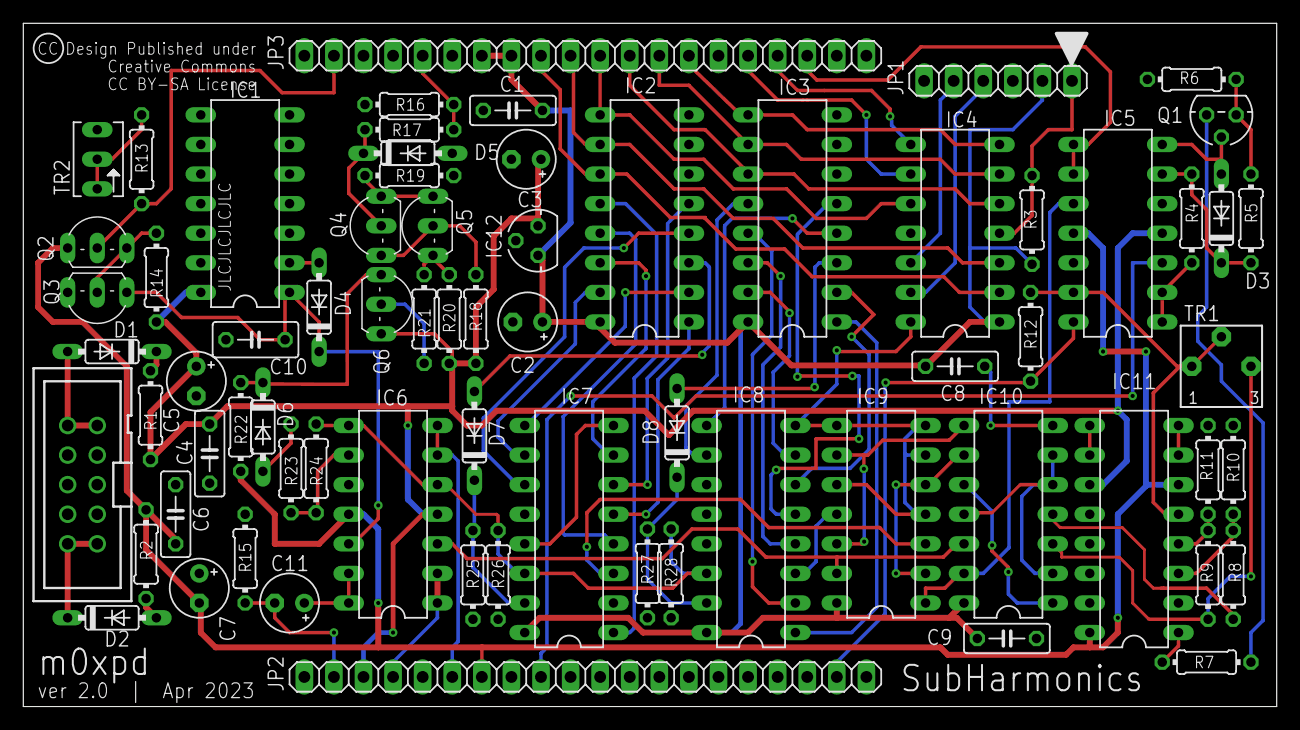
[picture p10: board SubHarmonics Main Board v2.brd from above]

Board: 2 copper layers, 107.6 x 58.7 mm, 71 parts (0 on the bottom side), 82 nets.

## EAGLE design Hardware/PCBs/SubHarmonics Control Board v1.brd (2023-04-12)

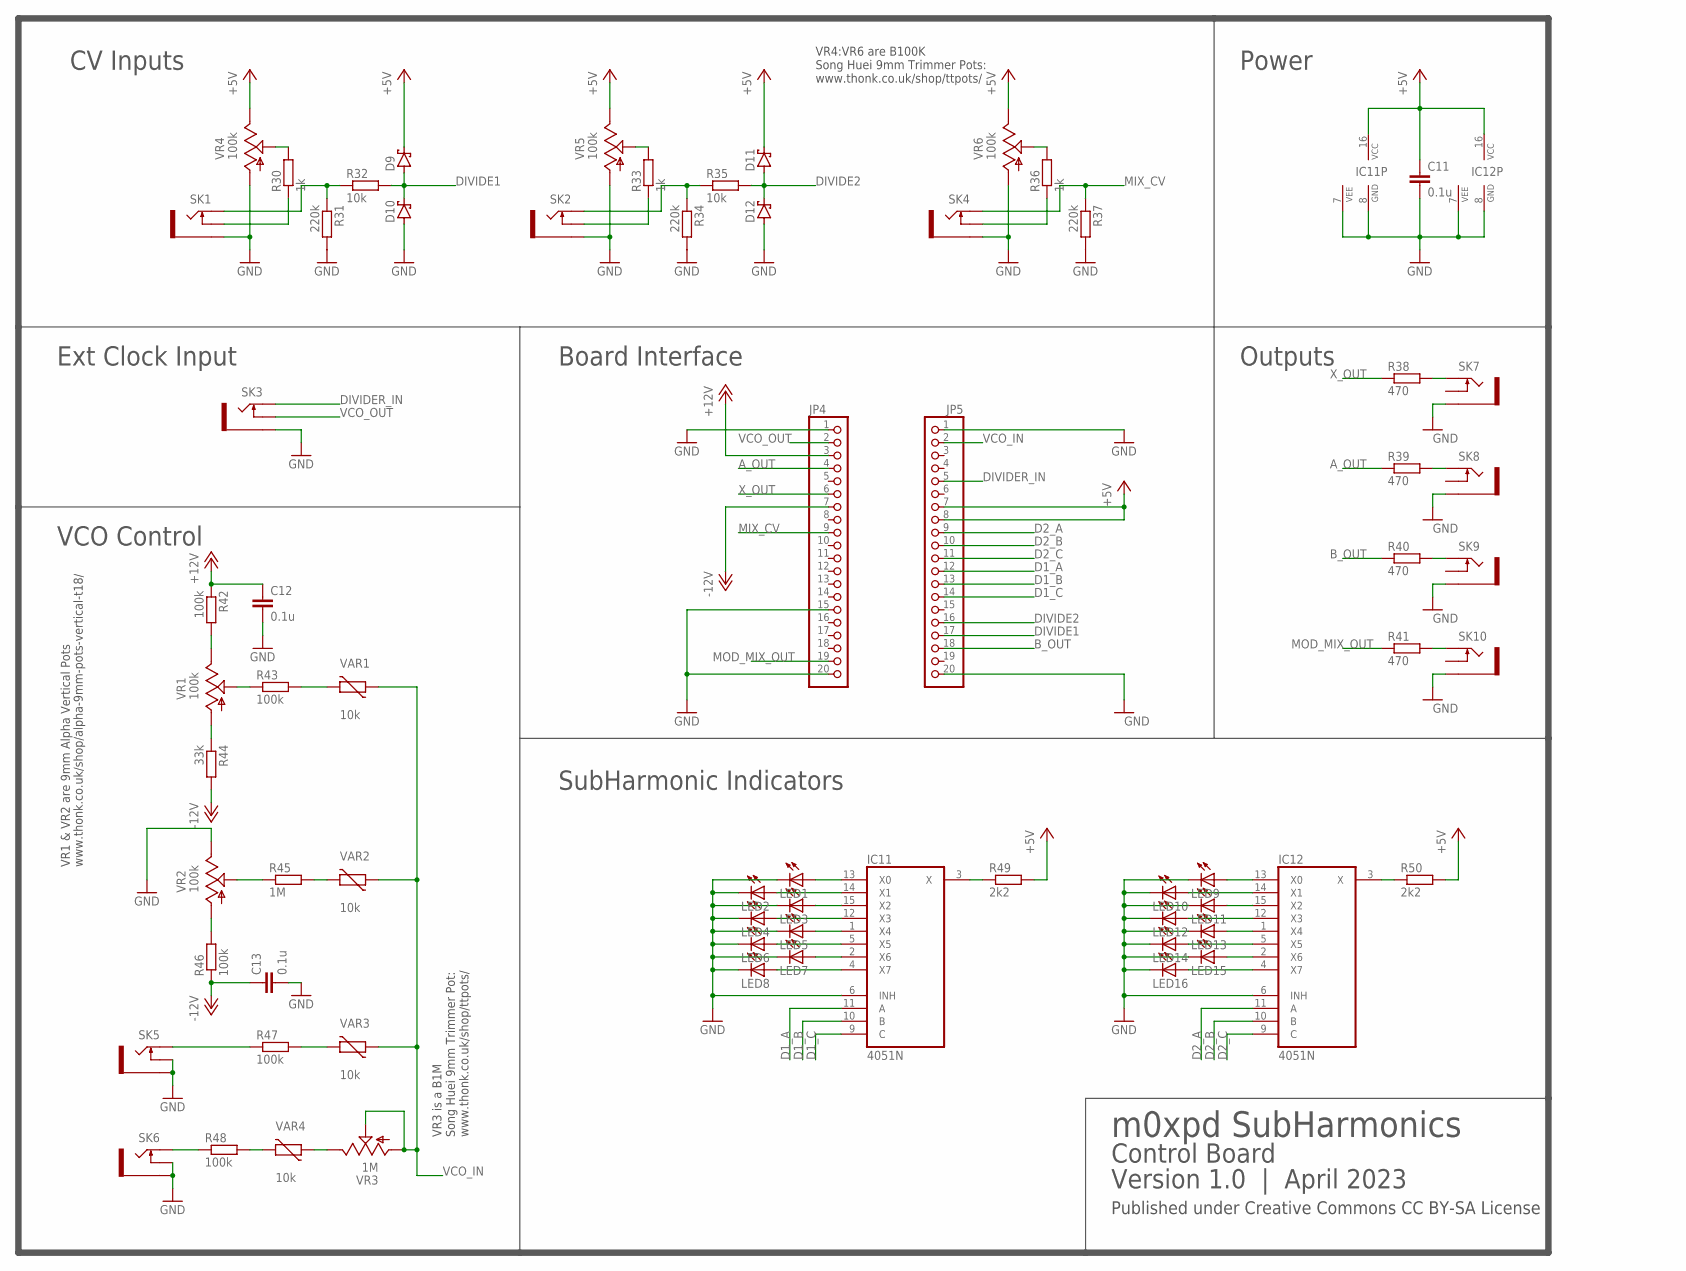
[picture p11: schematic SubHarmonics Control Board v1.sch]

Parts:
C11, C12, C13: 0.1u; C050-025X075
D9, D10, D11, D12: 1N5817-T; DO41-7.6
IC11, IC12: 4051N; DIL16
JP4, JP5: PINHD-1X20; 1X20
LED1, LED2, LED3, LED4, LED5, LED6, LED7, LED8, LED9, LED10, LED11, LED12, LED13, LED14, LED15, LED16: LED3MM
R30, R33, R36: 1k; 0204/7
R31, R34, R37: 220k; 0204/7
R32, R35: 10k; 0204/7
R38, R39, R40, R41: 470; 0204/7
R42, R43, R46, R47, R48: 100k; 0204/7
R44: 33k; 0204/7
R45: 1M; 0204/7
R49, R50: 2k2; 0204/7
SK1, SK2, SK3, SK4, SK5, SK6, SK7, SK8, SK9, SK10: THONKICONN_JACK; WQP-PJ301M-12_JACK
VAR1, VAR2, VAR3, VAR4: 10k; C025-024X044
VR1, VR2, VR4, VR5, VR6: 100k; 9MM_SNAP-IN_POT
VR3: 1M; 9MM_SNAP-IN_POT

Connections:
+5V: C11.1, D9.C, D11.C, IC11.16 (VCC), IC12.16 (VCC), JP5.7, JP5.8, R49.2, R50.2, VR4.3 (E), VR5.3 (E), VR6.3 (E)
+12V: C12.1, JP4.3, R42.1
-12V: C13.1, JP4.7, R44.2, R46.1
A_OUT: JP4.4, R39.1
B_OUT: JP5.18, R40.1
D1_A: IC11.11 (A), JP5.12
D1_B: IC11.10 (B), JP5.13
D1_C: IC11.9 (C), JP5.14
D2_A: IC12.11 (A), JP5.9
D2_B: IC12.10 (B), JP5.10
D2_C: IC12.9 (C), JP5.11
DIVIDE1: D9.A, D10.C, JP5.17, R32.2
DIVIDE2: D11.A, D12.C, JP5.16, R35.2
DIVIDER_IN: JP5.5, SK3.P$1_TIP (TIP)
GND: C11.2, C12.2, C13.2, D10.A, D12.A, IC11.6 (INH), IC11.7 (VEE), IC11.8 (GND), IC12.6 (INH), IC12.7 (VEE), IC12.8 (GND), JP4.1, JP4.15, JP4.20, JP5.1, JP5.20, LED1.K (C), LED2.K (C), LED3.K (C), LED4.K (C), LED5.K (C), LED6.K (C), LED7.K (C), LED8.K (C), LED9.K (C), LED10.K (C), LED11.K (C), LED12.K (C), LED13.K (C), LED14.K (C), LED15.K (C), LED16.K (C), R31.2, R34.2, R37.2, SK1.P$3_SLEEVE (SLEEVE), SK2.P$3_SLEEVE (SLEEVE), SK3.P$3_SLEEVE (SLEEVE), SK4.P$3_SLEEVE (SLEEVE), SK5.P$2_SWITCH (SWITCH), SK5.P$3_SLEEVE (SLEEVE), SK6.P$2_SWITCH (SWITCH), SK6.P$3_SLEEVE (SLEEVE), SK7.P$3_SLEEVE (SLEEVE), SK8.P$3_SLEEVE (SLEEVE), SK9.P$3_SLEEVE (SLEEVE), SK10.P$3_SLEEVE (SLEEVE), VR2.3 (E), VR4.1 (A), VR5.1 (A), VR6.1 (A)
MIX_CV: JP4.9, R37.1, SK4.P$1_TIP (TIP)
MOD_MIX_OUT: JP4.19, R41.1
unnamed: R38.2, SK7.P$1_TIP (TIP)
unnamed: R39.2, SK8.P$1_TIP (TIP)
unnamed: R40.2, SK9.P$1_TIP (TIP)
unnamed: R41.2, SK10.P$1_TIP (TIP)
unnamed: R30.1, SK1.P$2_SWITCH (SWITCH)
unnamed: R31.1, R32.1, SK1.P$1_TIP (TIP)
unnamed: R42.2, VR1.3 (E)
unnamed: R44.1, VR1.1 (A)
unnamed: R43.1, VR1.2 (S)
unnamed: R43.2, VAR1.2
unnamed: R47.2, VAR3.2
unnamed: R47.1, SK5.P$1_TIP (TIP)
unnamed: R46.2, VR2.1 (A)
unnamed: R45.1, VR2.2 (S)
unnamed: R45.2, VAR2.2
unnamed: R48.1, SK6.P$1_TIP (TIP)
unnamed: R48.2, VAR4.2
unnamed: VAR4.1, VR3.3 (E)
unnamed: R30.2, VR4.2 (S)
unnamed: R33.1, SK2.P$2_SWITCH (SWITCH)
unnamed: R34.1, R35.1, SK2.P$1_TIP (TIP)
unnamed: IC11.13 (X0), LED1.A
unnamed: IC11.14 (X1), LED2.A
unnamed: IC11.15 (X2), LED3.A
unnamed: IC11.12 (X3), LED4.A
unnamed: IC11.1 (X4), LED5.A
unnamed: IC11.5 (X5), LED6.A
unnamed: IC11.2 (X6), LED7.A
unnamed: IC11.4 (X7), LED8.A
unnamed: IC12.13 (X0), LED9.A
unnamed: IC11.3 (X), R49.1
unnamed: IC12.14 (X1), LED10.A
unnamed: IC12.15 (X2), LED11.A
unnamed: IC12.12 (X3), LED12.A
unnamed: IC12.1 (X4), LED13.A
unnamed: IC12.5 (X5), LED14.A
unnamed: IC12.2 (X6), LED15.A
unnamed: IC12.4 (X7), LED16.A
unnamed: R33.2, VR5.2 (S)
unnamed: IC12.3 (X), R50.1
unnamed: R36.1, SK4.P$2_SWITCH (SWITCH)
unnamed: R36.2, VR6.2 (S)
VCO_IN: JP5.2, VAR1.1, VAR2.1, VAR3.1, VR3.1 (A), VR3.2 (S)
VCO_OUT: JP4.2, SK3.P$2_SWITCH (SWITCH)
X_OUT: JP4.6, R38.1

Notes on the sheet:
m0xpd SubHarmonics
Control Board
Version 1.0 | April 2023
Published under Creative Commons CC BY-SA License
SubHarmonic Indicators
VCO Control
CV Inputs
Ext Clock Input
Board Interface
Power
Outputs
VR3 is a B1M Song Huei 9mm Trimmer Pot: www.thonk.co.uk/shop/ttpots/
VR4:VR6 are B100K Song Huei 9mm Trimmer Pots: www.thonk.co.uk/shop/ttpots/
VR1 & VR2 are 9mm Alpha Vertical Pots
www.thonk.co.uk/shop/alpha-9mm-pots-vertical-t18/

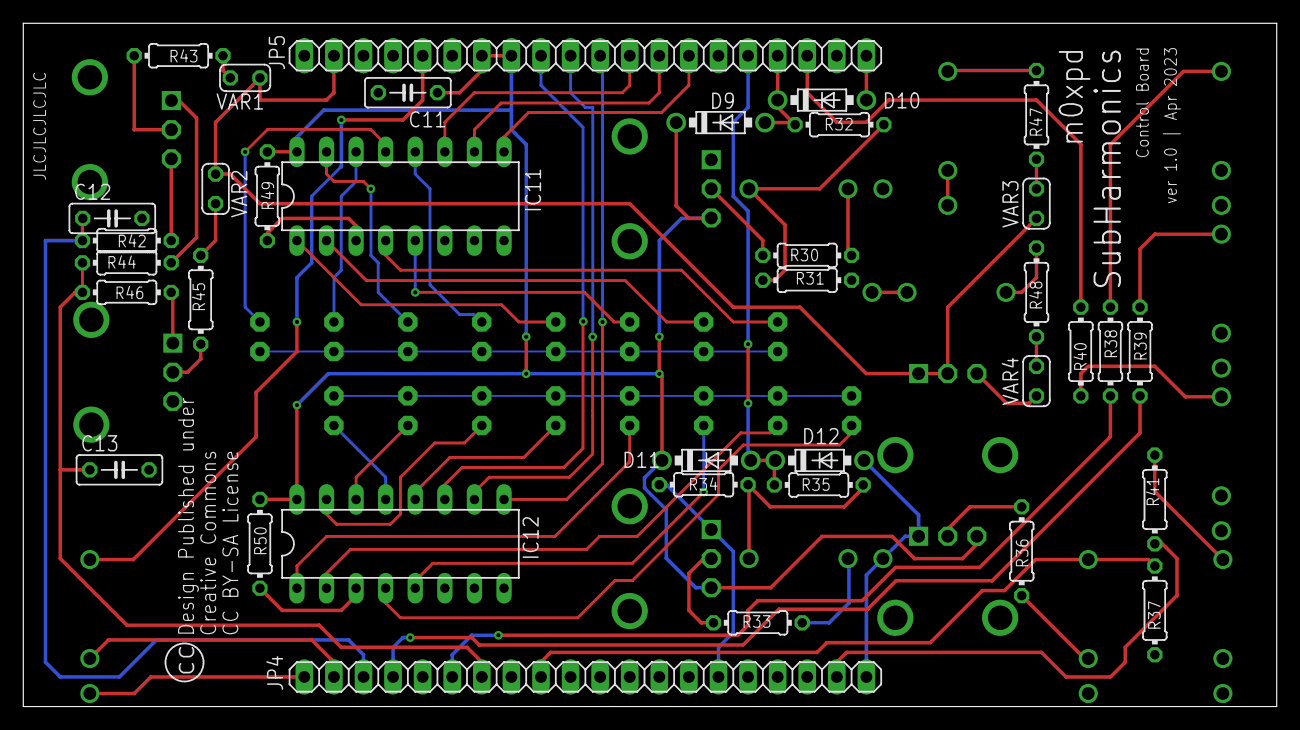
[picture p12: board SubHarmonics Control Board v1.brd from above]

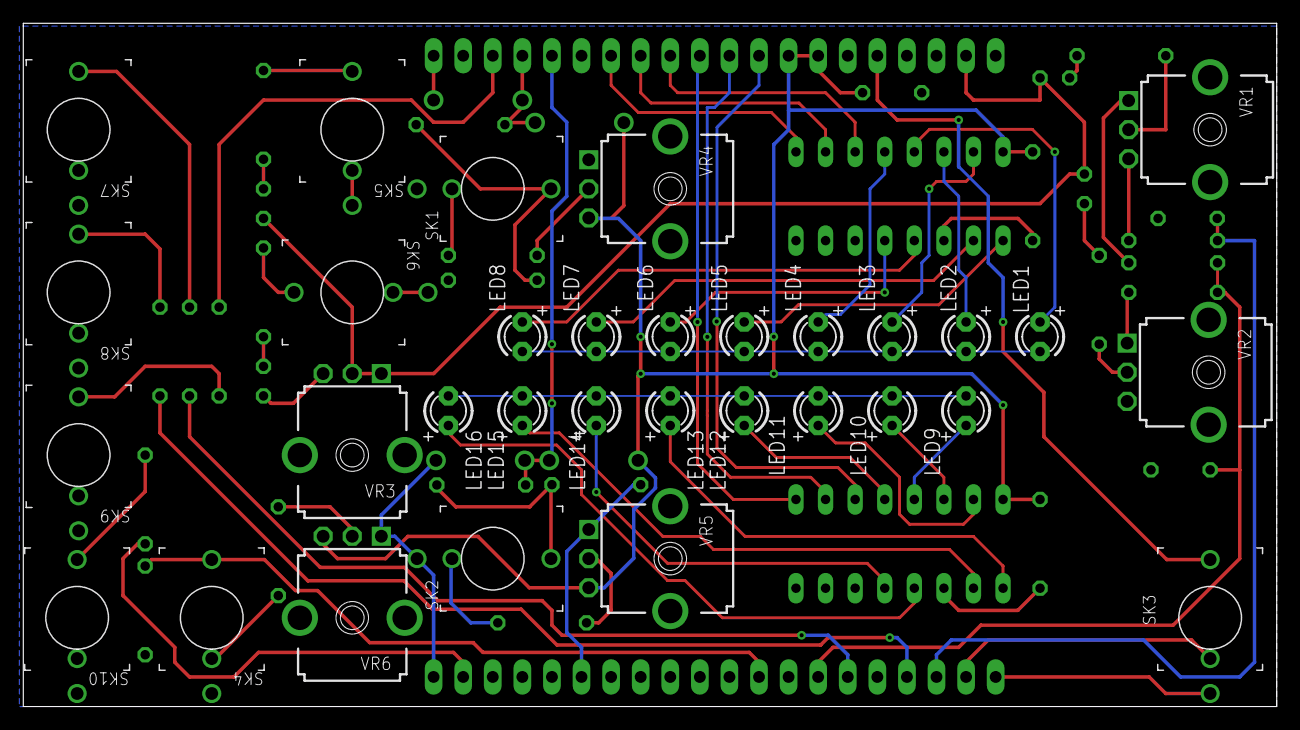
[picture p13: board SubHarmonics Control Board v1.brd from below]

Board: 2 copper layers, 107.6 x 58.7 mm, 68 parts (32 on the bottom side), 62 nets.

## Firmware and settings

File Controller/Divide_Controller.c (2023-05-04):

// Divide_Controller.c
//
// Software for the 'SubHarmonics' Harmonic Division VCO
// m0xpd
// 2023
// https://github.com/m0xpd/SubHarmonics
//
//
// PIC16F676 Configuration Bit Settings...

#pragma config FOSC = INTRCIO   // Oscillator Selection bits (INTOSC oscillator: I/O function on RA4/OSC2/CLKOUT pin, I/O function on RA5/OSC1/CLKIN)
#pragma config WDTE = OFF       // Watchdog Timer Enable bit (WDT disabled)
#pragma config PWRTE = OFF      // Power-up Timer Enable bit (PWRT enabled)
#pragma config MCLRE = ON       // RA3/MCLR pin function select (RA3/MCLR pin function is MCLR)
#pragma config BOREN = ON       // Brown-out Detect Enable bit (BOD enabled)
#pragma config CP = OFF         // Code Protection bit (Program Memory code protection is disabled)
#pragma config CPD = OFF        // Data Code Protection bit (Data memory code protection is disabled)


#include <xc.h>
#define _XTAL_FREQ 4000000

int Divide1 = 0;
int Divide2 = 0;
int voltage;

void ADC_Init()
{
  ADCON0 = 0x81; //ADC Module Turned ON and Clock is selected
  ADCON1 = 0b100; ; 
}

unsigned int ADC_Read(unsigned char channel)
{
  if(channel > 7)           //If Invalid channel selected 
    return 0;               //Return 0
  ADCON0 &= 0x81;               //Clear the Channel Selection Bits
  ADCON0 |= channel<<2;         //Setting the required Bits
  __delay_ms(2);                //time to charge hold capacitor
  GO_nDONE = 1;                 //Initializes A/D Conversion
  while(GO_nDONE);              //Wait for A/D Conversion to complete
  return ((ADRESH<<8)+ADRESL);  //Return Result
}

void setDiv1(){  // set Divider 1
    if(Divide1&1){
        RC5=1;
    }
    else{
        RC5=0;
    }
    if(Divide1&2){
        RC4=1;
    }
    else{
        RC4=0;
    }            
    if(Divide1&4){
        RC3=1;
    }
    else{
        RC3=0;
    }            
}

void setDiv2(){ // set Divider 2
    if(Divide2&1){
        RA5=1;
    }
    else{
        RA5=0;
    }
    if(Divide2&2){
        RA4=1;
    }
    else{
        RA4=0;
    }            
    if(Divide2&4){
        RC0=1;
    }
    else{
        RC0=0;
    }            
}
void main(){
    ANSEL=0X00;     // all pins are digital
    TRISC=0X00;
    TRISA=0X00;
                    // AN6 is analog input for Divide1 Potentiometer
    TRISC2 = 1;     // on RC2, pin 8 
                    // AN5 is analog input for DIVIDE 2 Potentiometer
    TRISC1 = 1;     // on RC1, pin 10
    ADC_Init();


    while(1){
    voltage=ADC_Read(0x6);      // Just loop round doing this...
    Divide1=voltage/128;  
    voltage=ADC_Read(0x5);
    Divide2=voltage/128;   
    setDiv1();
    setDiv2();
    __delay_ms(5);
    }
    
}

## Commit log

2023-04-12 Rename SubHarmonics Control Board v1.brd to Hardware/SubHarmonics Control Board v1.brd
    [SubHarmonics Control Board v1.brd]
2023-04-12 Rename SubHarmonics Control Board v1.sch to Hardware/SubHarmonics Control Board v1.sch
    [SubHarmonics Control Board v1.sch]
2023-04-12 Rename SubHarmonics Main Board v1.brd to Hardware/SubHarmonics Main Board v1.brd
    [SubHarmonics Main Board v1.brd]
2023-04-12 Rename SubHarmonics Main Board v1.sch to Hardware/SubHarmonics Main Board v1.sch
    [SubHarmonics Main Board v1.sch]
2023-05-03 Rename Hardware/SubHarmonics Front Panel.kicad_pcb to Hardware/FrontPanel/SubHarmonics Front Panel.kicad_pcb
    [SubHarmonics Front Panel.kicad_pcb]
2023-05-03 Rename Hardware/SubHarmonics Front Panel.kicad_pro to Hardware/FrontPanel/SubHarmonics Front Panel.kicad_pro
2023-05-03 Rename Hardware/SubHarmonics Front Panel.kicad_sch to Hardware/FrontPanel/SubHarmonics Front Panel.kicad_sch
    [SubHarmonics Front Panel.kicad_sch]
2023-05-04 Rename Hardware/SubHarmonics Control Board v1 BoM.txt to Hardware/PCBs/SubHarmonics Control Board v1 BoM.txt
2023-05-04 Rename Hardware/SubHarmonics Control Board v1.brd to Hardware/PCBs/SubHarmonics Control Board v1.brd
    [SubHarmonics Control Board v1.brd]
2023-05-04 Rename Hardware/SubHarmonics Control Board v1.sch to Hardware/PCBs/SubHarmonics Control Board v1.sch
    [SubHarmonics Control Board v1.sch]
2023-05-04 Rename Hardware/SubHarmonics Main Board v2 BoM.txt to Hardware/PCBs/SubHarmonics Main Board v2 BoM.txt
2023-05-04 Rename Hardware/SubHarmonics Main Board v2.brd to Hardware/PCBs/SubHarmonics Main Board v2.brd
    [SubHarmonics Main Board v2.brd]
2023-05-04 Rename Hardware/SubHarmonics Main Board v2.sch to Hardware/PCBs/SubHarmonics Main Board v2.sch
    [SubHarmonics Main Board v2.sch]
2023-10-22 Rename Hardware/SubHarmonics Main Board BoM v3.txt to Hardware/PCBs/SubHarmonics Main Board BoM v3.txt
2023-10-22 Rename Hardware/SubHarmonics Main Board v3.brd to Hardware/PCBs/SubHarmonics Main Board v3.brd
    [SubHarmonics Main Board v3.brd]
2023-10-22 Rename Hardware/SubHarmonics Main Board v3.sch to Hardware/PCBs/SubHarmonics Main Board v3.sch
    [SubHarmonics Main Board v3.sch]
2023-10-22 Rename Hardware/SubHarmonics Main Board BoM v2.txt to Hardware/PCBs/SubHarmonics Main Board BoM v2.txt
2023-10-22 Update and rename temp.txt to Input Stage Behaviour.md
2023-10-22 Update Input Stage Behaviour.md
2023-10-22 Update and rename Input Stage Behaviour.md to Input Stage Switching Behaviour.md
2023-10-22 Update Input Stage Switching Behaviour.md

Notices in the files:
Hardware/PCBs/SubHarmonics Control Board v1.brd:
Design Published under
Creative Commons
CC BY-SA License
